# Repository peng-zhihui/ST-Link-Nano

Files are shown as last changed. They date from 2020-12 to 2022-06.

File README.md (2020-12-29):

# ST-Link-Nano
> 自制超迷你的ST-Link模块。

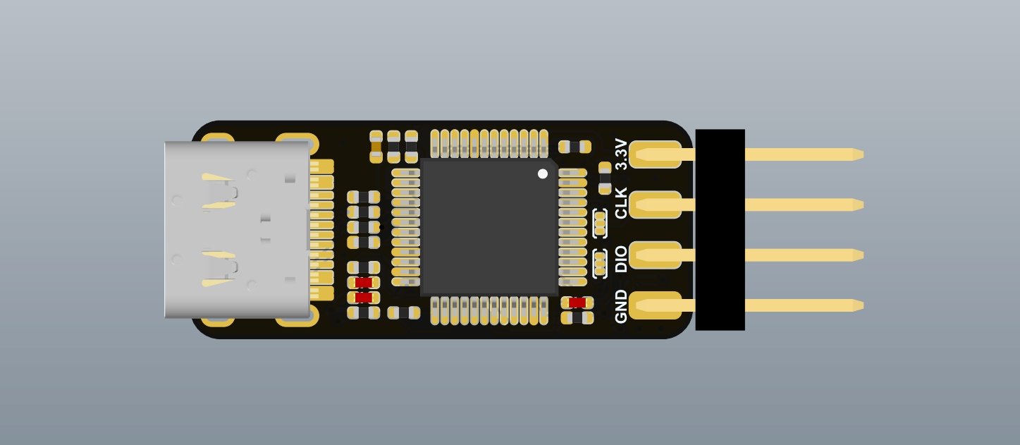
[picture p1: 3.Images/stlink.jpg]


跟我之前做的DAPLink基本一致，基于ST-Link V2版本硬件修改而成。没有什么特殊的功能，就是个人使用Clion做STM32开发时，OpenOCD对于ST-Link的支持比DAPLink要好（兼容的芯片型号、下载速度），所以额外又设计了一个下载器。

下载器芯片用的是STM32F103CBT6，带一个虚拟串口功能，可以同时作为ST-Link和USB转串口模块使用，同时带一个U盘下载固件功能。

## 使用方法

板子上有两个跳线焊盘，分别连接到STM32F103的SWD引脚，以及作为ST-Link时的SWD引脚。所以在焊好之后，先跳线选择到`STM32F103`的SWD引脚，给STM32下载仓库的Bootloader固件（用`STLink-Utility`等软件）；之后用`ST-LinkUpgrade`软件升级即可，可选择（stm32 debug + VCP + MSD）；然后再把跳线跳到另外一边，就可以正常当ST-Link用了。

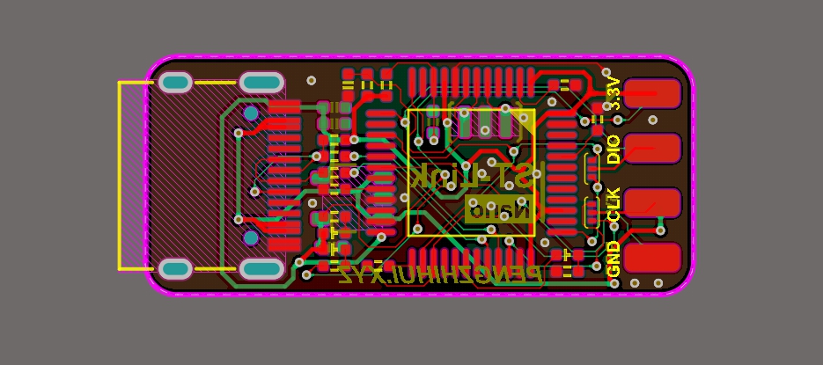
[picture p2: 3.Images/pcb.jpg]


## 跳线说明

* 先按红色的连线跳线，用另一个J-Link或者ST-Link给本板子下载BootLoader
* 然后跳到蓝色的跳线（保持本板子的USB和电脑的连接），用`ST-LinkUpgrade`软件升级固件
* 重新上电即可正常使用（没装驱动的话可以装一下仓库提供的官方驱动），可以在设备管理器看到ST-Link设备和一个COM口

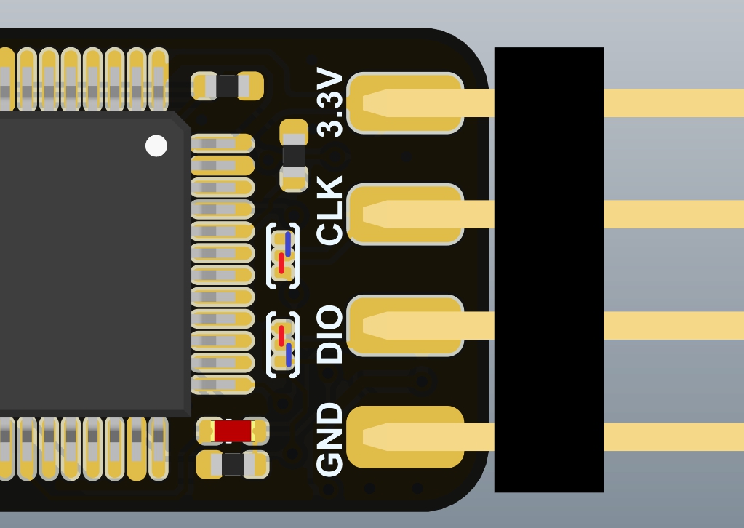
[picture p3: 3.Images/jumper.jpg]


> 焊接好的实物照片，硬件功能已验证没有问题👇

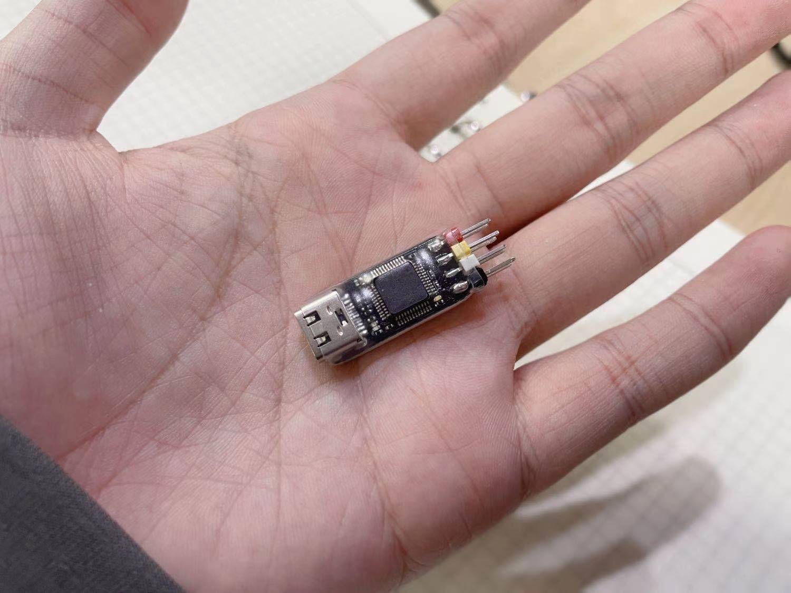
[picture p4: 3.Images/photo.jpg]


### Enjoy~记得给仓库点星星

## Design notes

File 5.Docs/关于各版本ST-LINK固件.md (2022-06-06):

## 前言

某宝上的STLINK V2下载器偶尔会坏掉，我们尝试修复一下



## 1.材料

（1）完好的STLINK V2下载器和坏掉的下载器各1个；

（2）固件：https://gitee.com/Cai-Zi/stm32f103c8t6_dap_swo，也可以使用蓝色板制作哦



## 2.硬件

### 2.1原理图

此下载器的2x5P接口中，SWD接口为：**SWDIO-PB14，SWCLK-PB13**

> 笔者的下载器主控芯片是64Pin，无法烧录固件，猜测是芯片挂了，于是找了片**STM32F103R8T6**焊接了上去



### 2.2固件引脚说明



## 3.烧录固件

将坏掉的下载器、完好的下载器和电脑连接好；



打开STM32 ST-LINK Utility，进行连接；

 

点击Target》Program...，找到下载好的[F103-DAP-SWO-CDC-STLINK_V20-SWO_PA10.hex](https://gitee.com/Cai-Zi/stm32f103c8t6_dap_swo/blob/master/Hex/F103-DAP-SWO-CDC-STLINK_V20-SWO_PA10.hex)，烧录即可。

点击并拖拽以移动

## 4.驱动配置

下载[UsbDriverTool](https://visualgdb.com/UsbDriverTool/)，如图安装WinUSB驱动



安装好后，设备管理器出现3种设备，Done！



## 5.使用DAPLink调试

keil工程里，魔术棒设置如下
图片

勾选SWJ，Port选择SW，Connect选择Normal，Reset选择SYSRESETREQ
图片

## 6.关于ST-LINK

参考[ST官方文档](https://www.st.com/content/ccc/resource/technical/document/technical_note/group0/30/c8/1d/0f/15/62/46/ef/DM00290229/files/DM00290229.pdf/jcr:content/translations/en.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)，官方推出了三大版本：V1、V2和V3

> 几个ST-LINK共存版本是随着时间的推移不断增加新功能的结果，
> 从第一个ST-LINK/V1版本开始。本节简要介绍了版本命名。
> ST-LINK的前两个版本都是独立的，并且嵌入了STMicroelectronics Discovery和Eval开发板。这些版本是：
> •ST-LINK/V1（现已过时）
> •ST-LINK/V2
>
> 第三个ST-LINK版本，ST-LINK/V2-1，是ST-LINK/V2的一个改进，增加了USB接口（存储接口和虚拟COM端口）以及更好的电源管理控制
> 申请委员会。ST-LINK/V2-1部署在最近的STMicroelectronics Discovery、Eval和Nucleo开发板。
> 另外两个版本是从ST-LINK/V2版本派生的，为了支持ST-LINK/V2-1的一些功能：
>
> •ST-LINK/V2-A，用于大容量存储
> •ST-LINK/V2-B，用于大容量存储和虚拟COM端口
> STLINK-V3是最新和最强大的ST-LINK代。它首先作为一个模块化的单机版引入探针（STLINK-V3SET）被改编成更紧凑的衍生物（STLINK-V3MINI和STLINK-V3MODS），可能也可嵌入演示板（STLINK-V3E）。STLINK-V3具有专门开发的多路径USB网桥功能。
> 各种ST-LINK实现嵌入了基于Arm® Cortex®‑M的STM32位微控制器。



- ST-Link/V2：支持STM32和STM8调试，不带虚拟串口，TB上卖的大多是这种，目前手头还有好几个这个版本的ST-Link。后面会使用这个版本进行烧录。
- ST-LinkV2-1: 支持STM32调试，带虚拟串口和虚拟U盘下载，目前ST官方的Nucleo系列评估板上面板载的ST-Link就是这个版本。

## 参考链接

- [STM32F103C8T6_CMSIS-DAP_SWO](https://github.com/RadioOperator/STM32F103C8T6_CMSIS-DAP_SWO)
- [CMSIS-DAP](https://github.com/x893/CMSIS-DAP)
- [nanoDAP](https://github.com/wuxx/nanoDAP)
- [ST_LINK-V2_1](https://www.oshwhub.com/CYIIOT/ST_LINK-V2_1)

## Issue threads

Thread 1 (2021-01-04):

稚晖君啥时候整个j-link V9 Nano？

anarah, 2021-01-04:
ST家芯片价格暴涨，换用GD32了，STlink就用不了了，还是jlink通用一点
https://github.com/konosubakonoakua/Various_MCU_Debugger_DIY
这儿一堆资料，里面那个mini版的jlink实际打样出来reset有问题，大佬啥时候有空搞搞呀

XuBovey, 2021-01-08:
那你都说可以放心大板了，嗯~ o(*￣▽￣*)o？

anarah, 2021-01-08:
> 那你都说可以放心大板了，嗯~ o(_￣▽￣_)o？

他是这么说的，然而实际打板发现有问题

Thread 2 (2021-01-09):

Hex firmware

jason416, 2021-01-09:
Hi zhihui, I can only use **UART1** to download firmware but require firmware in **ihex** format.
Could you please upload it to this repo?

jason416, 2021-01-09:
I found a tool - **Flash_Loader_Demonstrator_v2.6.0**, which can flash firmware of **bin** format.
I am closing this issue, just ignore...

Closed 2021-01-09.

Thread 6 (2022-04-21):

这个stlink一定要用f103cbt6吗？f103c8t6能不能用？

tai-youli, 2022-04-21:
看了里面只有一个BootLoader.bin文件，大小是16KB，我不太确定c8t6的64kb够不够用。是直接烧录进去就行了吗？

peng-zhihui, 2022-04-21:
可以，一样的

tai-youli, 2022-04-22:
> 可以，一样的

ohhhhh!!!  大佬回我了！ 昨天收到邮件激动了一晚上！   板子已经下单开打了！元器件也已经买好了！突然我就充满动力了！

   感谢稚晖大佬回复！追随你脚步的路上突然充满动力！我会更多的复刻你的作品并做出创新，越来越接近你的高度的！

tai-youli, 2022-04-22:
> 可以，一样的

ohhhhh!!!  大佬回我了！ 昨天收到邮件激动了一晚上！   板子已经下单开打了！元器件也已经买好了！突然我就充满动力了！

   感谢稚晖大佬回复！追随你脚步的路上突然充满动力！我会更多的复刻你的作品并做出创新，越来越接近你的高度的！

Closed 2022-04-22.

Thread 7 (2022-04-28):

[Help] 用CC线无法识别ST-Link,但是USBA-typeC可以正常使用

Last-ID, 2022-04-28:
如题，CC1，CC2口无下拉电阻无法正常供电，添加5.1K下拉电阻后，可以正常供电，但是无法识别到stlink

**在实际复刻过程中，为了方便焊接，更改了连接器母座型号**，下图为16Pin Type-C母座原理图，其他部分电路与稚晖君的保持一致
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

peng-zhihui, 2022-04-28:
你这图里3个USB_P，明显是原理图画错了啊

Last-ID, 2022-05-23:
OK，把线纠正过来之后加了俩下拉电阻，CC线可以正常使用了
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

Closed 2022-05-23.

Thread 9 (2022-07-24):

离线烧录器开源吗

XUEN-1, 2022-07-24:
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
大佬关于这个集成了离线下载，can，电压表，逻辑分析仪的小工具，有什么开源的计划吗

peng-zhihui, 2022-07-25:
暂时没有，这是帮Xikii做的一个方案，他键盘量产需要离线更新固件，所以顺便给他做了个小设备。

XUEN-1, 2022-07-25:
> 暂时没有，这是帮Xikii做的一个方案，他键盘量产需要离线更新固件，所以顺便给他做了个小设备。

期待一下，毕竟这个又能水一期视频（其实是这个真的好看）

Ijxuan, 2022-07-25:
期待大佬开源,真的很喜欢这个离线下载功能,越看越喜欢

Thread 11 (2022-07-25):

烧录固件和更新驱动并将条线重新短接，链接电脑无法识别出ST-LINK，请问是出现了什么问题

zhongziqiang001, 2022-07-25:
求大佬翻牌

peng-zhihui, 2022-07-25:
再试一下吧，检查硬件焊接，正常不会有问题的

ufo250120, 2022-08-03:
我的固件升级完下载了两次后在用的时候就发现无法识别到usb设备，不明白是啥问题

snoooopy, 2022-08-05:
我也是遇到了同样的问题，检查了板子的焊接应该没问题，烧录stlink的bootloader后插上电脑端USB，就是无法识别的usb设备，目前也没有找到原因在哪里。

Yan-Zihao, 2022-10-22:
> 再试一下吧，检查硬件焊接，正常不会有问题的

请问下，说明里面一开始说的是：
先跳线到一侧->bootloader->软件升级->跳另一侧使用。
下面跳线说明说的是：
先跳线到一侧->bootloader->跳另一侧->软件升级->使用。

请问下是哪种操作对，谢谢~

salamiGeek, 2023-03-16:
看看原理图，看看PCB文件吧。大佬应该是更新过PCB文件了，但是没更新readme

VictorSnow, 2024-02-20:
我这边用国产的有这个问题，我用官方的芯片是正常的

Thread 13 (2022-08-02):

使用Type-C To Type-C 线无法供电的问题及解决方案

OLGZO, 2022-08-02:
之前在测试的时候因为没有多余的USB-A口，使用了Type-C To Type-C 线进行连接，发现因为没有配置CC线而导致无法供电的情况，建议在C口的CC线位置各增加5K1 的下拉电阻。
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

GreatDan, 2023-02-05:
我加了cc对地电阻，但是还是没效果。效果是vbus和gnd之间的led一直闪。

GreatDan, 2023-02-09:
问题解决的，楼主的方案没问题，但是要买全功能的typeC to typeC线，一般要20rmb左右，买几块钱一根的兼容线就是我上面那个效果。

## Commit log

2020-12-23 Init repo.
    [Main.SchDoc, ST-Link.PcbDoc, ST-Link.PrjPCB]
2020-12-28 [Hw] Fixed DIO & CLK pin silk error.
    [Main.SchDoc, ST-Link.PcbDoc, ST-Link.PrjPCB]
2020-12-29 [Tools] Add ST-Link driver.
2020-12-29 [Hw] Make Tx & Rx indicate LED brighter.
    [Main.SchDoc, ST-Link.PcbDoc, ST-Link.PrjPCB]
2020-12-29 [Hw] Nothing big deal, adjust silk.
    [ST-Link.PcbDoc]
